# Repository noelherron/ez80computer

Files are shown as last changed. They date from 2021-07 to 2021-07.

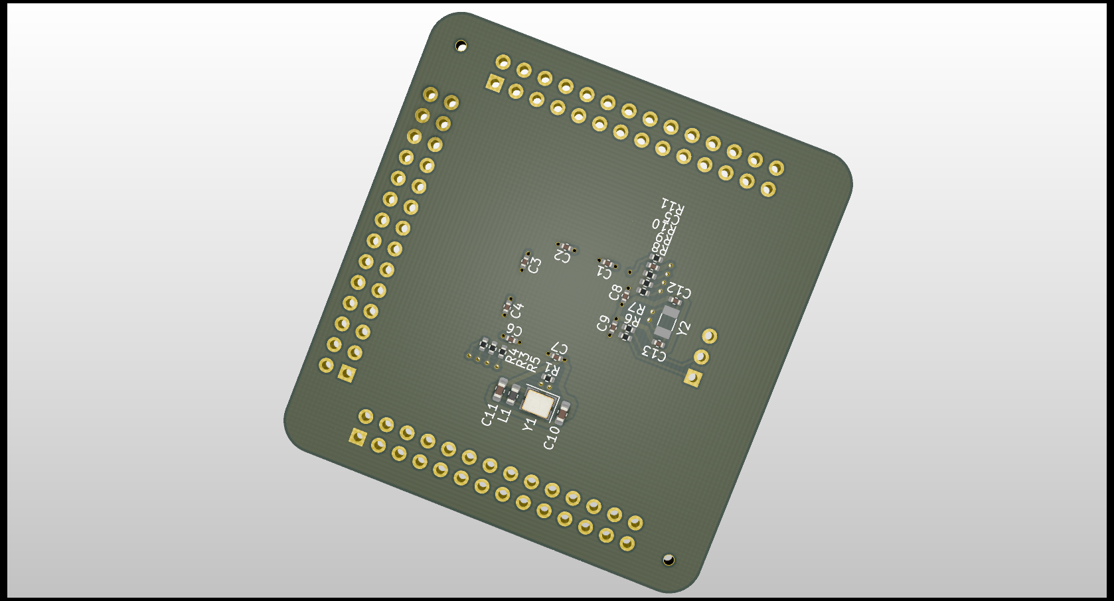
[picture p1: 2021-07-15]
rev0/eZ80SBCrev0.png

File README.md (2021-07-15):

# eZ80Computer

This is a single board computer based on the Zilog eZ80 microcontroller.

The eZ80 was chosen because it is an interesting microcontroller with a deep history.

It's CPU is based on the Z80, which was very popular in the 1980s, and is still manufactured today.

The eZ80 is distinct from many other microcontrollers because it has an exposed address and data bus.

Most microcontrollers have built in memory and omit these pins.

This means we can design our own memory scheme, and learn about things like bus mastering.

Like a traditional microcontroller, it still has many built in periferals, which keeps things small and simple.

This is a learning project for me to better understand electronics, PCB design, and computer system design.

I have already spent many hours in KiCad and had a batch of prototypes made.

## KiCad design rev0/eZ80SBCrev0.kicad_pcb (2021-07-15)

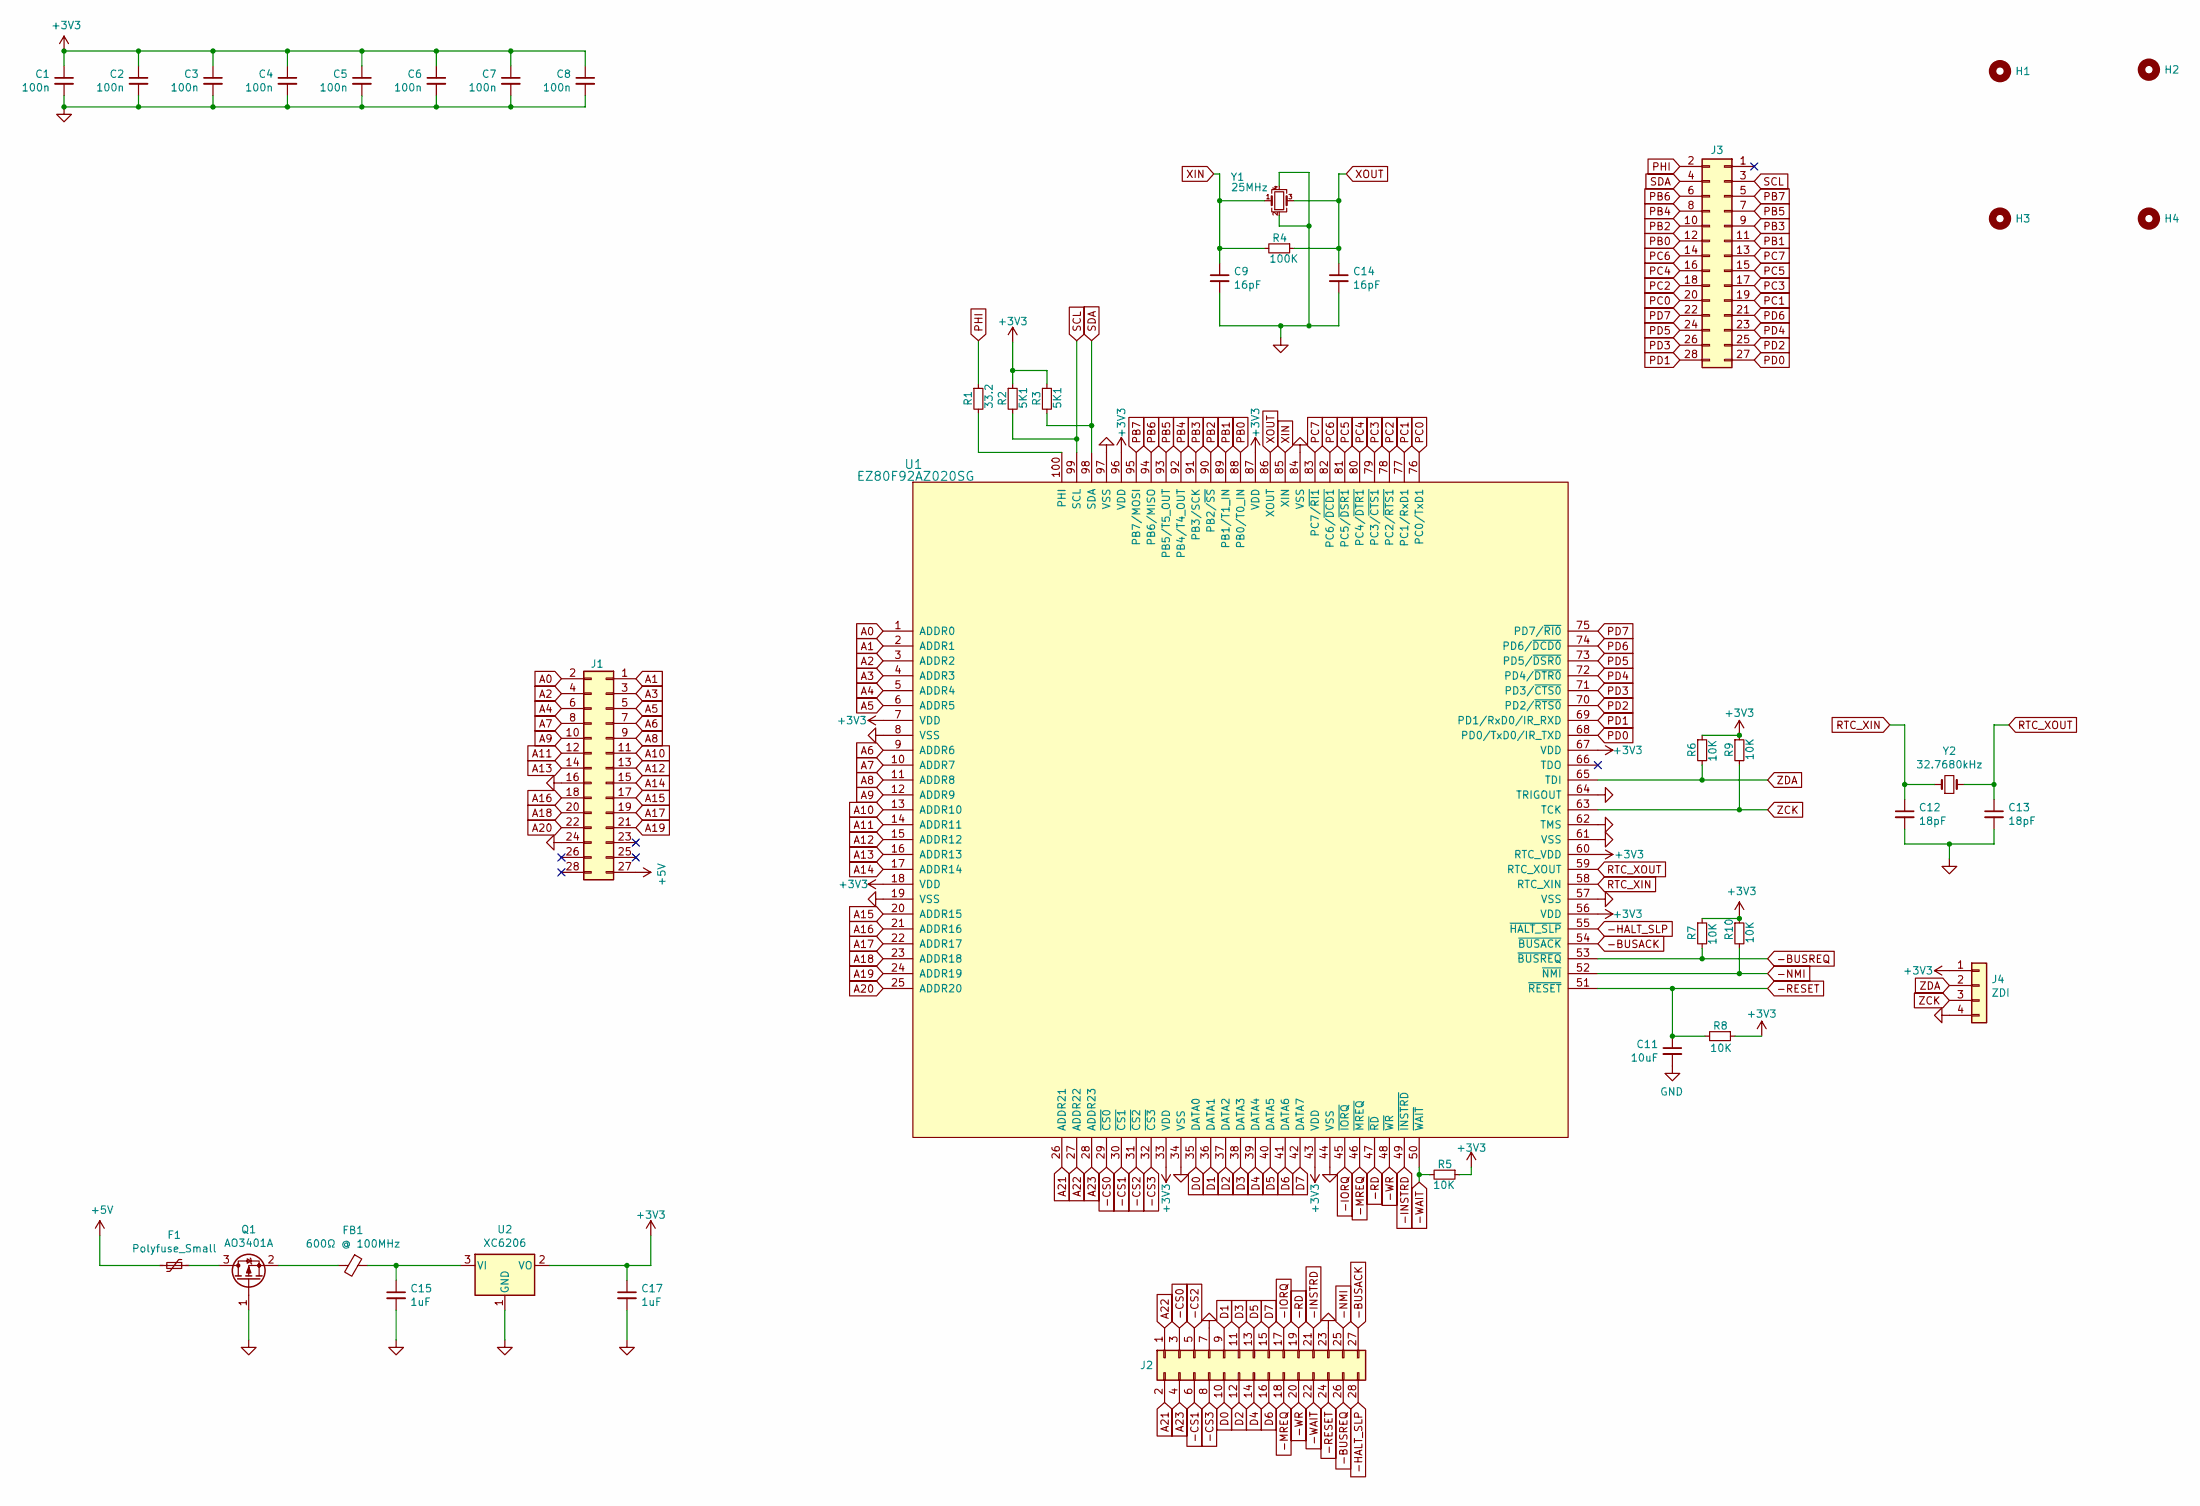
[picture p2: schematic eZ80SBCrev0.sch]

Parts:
C1, C2, C3, C4, C5, C6, C7, C8: 100n; C_0402_1005Metric; MFR. PART# CL05B104KO5NNNC; LCSC C1525
C9, C14: 16pF; C_0805_2012Metric; LCSC C1794
C11: 10uF; C_0402_1005Metric; MFR. PART# CL05A106MQ5NUNC; LCSC C15525
C12, C13: 18pF; C_0402_1005Metric; LCSC C1549
C15, C17: 1uF; C_0805_2012Metric; LCSC C28323
F1: Polyfuse_Small; Fuse_0805_2012Metric
FB1: 600Ω @ 100MHz; L_0805_2012Metric; LCSC C1017
H1, H2, H3, H4: MountingHole; MountingHole_2.1mm
J1, J2, J3: Conn_02x14_Top_Bottom; PinSocket_2x14_P2.54mm_Vertical
J4: ZDI; PinHeader_1x04_P2.54mm_Vertical
Q1: AO3401A; SOT-23; LCSC C15127
R1: 33.2; R_0402_1005Metric; MFR. PART# 0402WGF5101TCE; LCSC C25905
R2, R3: 5K1; R_0402_1005Metric; MFR. PART# 0402WGF5101TCE; LCSC C25905
R4: 100K; R_0805_2012Metric; LCSC C17407
R5, R6, R7, R8, R9, R10: 10K; R_0402_1005Metric; MFR. PART# 0402WGF1002TCE; LCSC C25744
U1: EZ80F92AZ020SG; LQFP-100_14x14mm_P0.5mm
U2: XC6206; SOT-23; LCSC C5446
Y1: 25MHz; SMD-5032-4P; LCSC C9006
Y2: 32.7680kHz; Crystal_SMD_3215-2Pin_3.2x1.5mm; LCSC C32346

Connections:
+3V3: C1.1, C2.1, C3.1, C4.1, C5.1, C6.1, C7.1, C8.1, C17.1, J4.1, R2.1, R3.1, R5.1, R6.1, R7.1, R8.1, R9.1, R10.1, U1.7 (VDD), U1.18 (VDD), U1.33 (VDD), U1.43 (VDD), U1.56 (VDD), U1.60 (RTC_VDD), U1.67 (VDD), U1.87 (VDD), U1.96 (VDD), U2.2 (VO)
+5V: F1.2, J1.27
-BUSACK: J2.27, U1.54 (~BUSACK)
-BUSREQ: J2.26, R7.2, U1.53 (~BUSREQ)
-CS0: J2.3, U1.29 (~CS0)
-CS1: J2.6, U1.30 (~CS1)
-CS2: J2.5, U1.31 (~CS2)
-CS3: J2.8, U1.32 (~CS3)
-HALT_SLP: J2.28, U1.55 (~HALT_SLP)
-INSTRD: J2.21, U1.49 (~INSTRD)
-IORQ: J2.17, U1.45 (~IORQ)
-MREQ: J2.18, U1.46 (~MREQ)
-NMI: J2.25, R10.2, U1.52 (~NMI)
-RD: J2.19, U1.47 (~RD)
-RESET: C11.1, J2.24, R8.2, U1.51 (~RESET)
-WAIT: J2.22, R5.2, U1.50 (~WAIT)
-WR: J2.20, U1.48 (~WR)
A0: J1.2, U1.1 (ADDR0)
A1: J1.1, U1.2 (ADDR1)
A2: J1.4, U1.3 (ADDR2)
A3: J1.3, U1.4 (ADDR3)
A4: J1.6, U1.5 (ADDR4)
A5: J1.5, U1.6 (ADDR5)
A6: J1.7, U1.9 (ADDR6)
A7: J1.8, U1.10 (ADDR7)
A8: J1.9, U1.11 (ADDR8)
A9: J1.10, U1.12 (ADDR9)
A10: J1.11, U1.13 (ADDR10)
A11: J1.12, U1.14 (ADDR11)
A12: J1.13, U1.15 (ADDR12)
A13: J1.14, U1.16 (ADDR13)
A14: J1.15, U1.17 (ADDR14)
A15: J1.17, U1.20 (ADDR15)
A16: J1.18, U1.21 (ADDR16)
A17: J1.19, U1.22 (ADDR17)
A18: J1.20, U1.23 (ADDR18)
A19: J1.21, U1.24 (ADDR19)
A20: J1.22, U1.25 (ADDR20)
A21: J2.2, U1.26 (ADDR21)
A22: J2.1, U1.27 (ADDR22)
A23: J2.4, U1.28 (ADDR23)
D0: J2.10, U1.35 (DATA0)
D1: J2.9, U1.36 (DATA1)
D2: J2.12, U1.37 (DATA2)
D3: J2.11, U1.38 (DATA3)
D4: J2.14, U1.39 (DATA4)
D5: J2.13, U1.40 (DATA5)
D6: J2.16, U1.41 (DATA6)
D7: J2.15, U1.42 (DATA7)
GND: C1.2, C2.2, C3.2, C4.2, C5.2, C6.2, C7.2, C8.2, C9.2, C11.2, C12.2, C13.2, C14.2, C15.2, C17.2, J1.16, J1.24, J2.7, J2.23, J4.4, Q1.1 (G), U1.8 (VSS), U1.19 (VSS), U1.34 (VSS), U1.44 (VSS), U1.57 (VSS), U1.61 (VSS), U1.62 (TMS), U1.64 (TRIGOUT), U1.84 (VSS), U1.97 (VSS), U2.1 (GND), Y1.2, Y1.4
unnamed: C15.1, FB1.1, U2.3 (VI)
unnamed: F1.1, Q1.3 (D)
unnamed: FB1.2, Q1.2 (S)
unnamed: R1.2, U1.100 (PHI)
PB0: J3.12, U1.88 (PB0/T0_IN)
PB1: J3.11, U1.89 (PB1/T1_IN)
PB2: J3.10, U1.90 (PB2/~SS)
PB3: J3.9, U1.91 (PB3/SCK)
PB4: J3.8, U1.92 (PB4/T4_OUT)
PB5: J3.7, U1.93 (PB5/T5_OUT)
PB6: J3.6, U1.94 (PB6/MISO)
PB7: J3.5, U1.95 (PB7/MOSI)
PC0: J3.20, U1.76 (PC0/TxD1)
PC1: J3.19, U1.77 (PC1/RxD1)
PC2: J3.18, U1.78 (PC2/~RTS1)
PC3: J3.17, U1.79 (PC3/~CTS1)
PC4: J3.16, U1.80 (PC4/~DTR1)
PC5: J3.15, U1.81 (PC5/~DSR1)
PC6: J3.14, U1.82 (PC6/~DCD1)
PC7: J3.13, U1.83 (PC7/~RI1)
PD0: J3.27, U1.68 (PD0/TxD0/IR_TXD)
PD1: J3.28, U1.69 (PD1/RxD0/IR_RXD)
PD2: J3.25, U1.70 (PD2/~RTS0)
PD3: J3.26, U1.71 (PD3/~CTS0)
PD4: J3.23, U1.72 (PD4/~DTR0)
PD5: J3.24, U1.73 (PD5/~DSR0)
PD6: J3.21, U1.74 (PD6/~DCD0)
PD7: J3.22, U1.75 (PD7/~RI0)
PHI: J3.2, R1.1
RTC_XIN: C12.1, U1.58 (RTC_XIN), Y2.1
RTC_XOUT: C13.1, U1.59 (RTC_XOUT), Y2.2
SCL: J3.3, R2.2, U1.99 (SCL)
SDA: J3.4, R3.2, U1.98 (SDA)
XIN: C9.1, R4.2, U1.85 (XIN), Y1.1
XOUT: C14.1, R4.1, U1.86 (XOUT), Y1.3
ZCK: J4.3, R9.2, U1.63 (TCK)
ZDA: J4.2, R6.2, U1.65 (TDI)

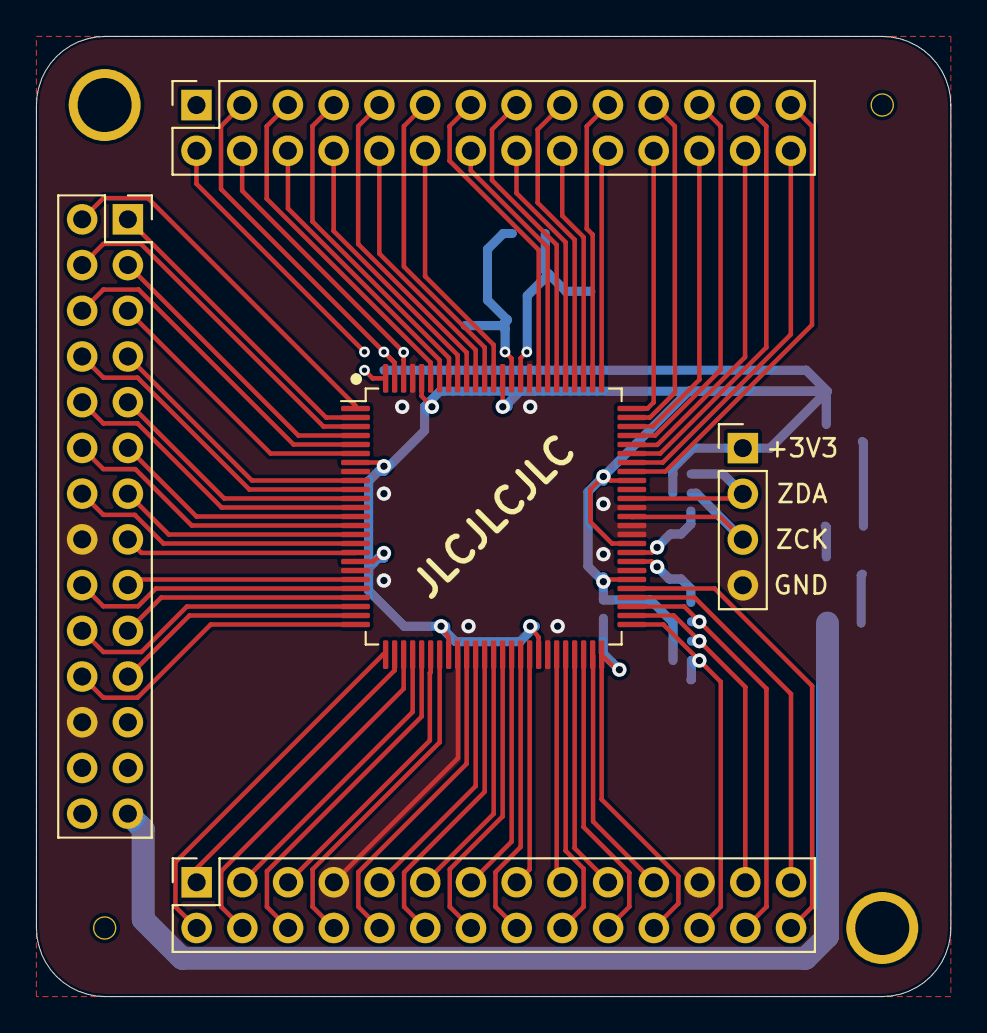
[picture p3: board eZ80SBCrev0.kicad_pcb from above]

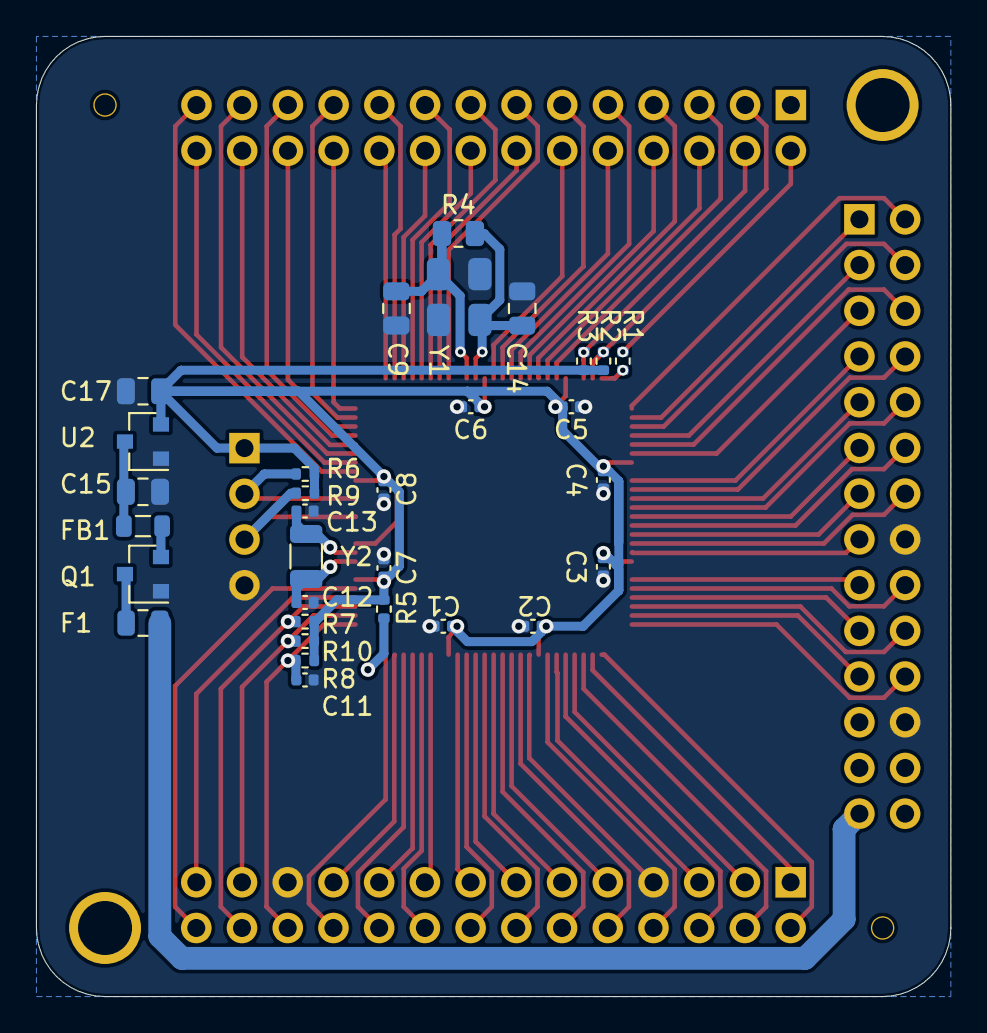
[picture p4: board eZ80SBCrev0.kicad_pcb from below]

Board: 2 copper layers, 50.8 x 53.3 mm, 40 parts (31 on the bottom side), 87 nets.

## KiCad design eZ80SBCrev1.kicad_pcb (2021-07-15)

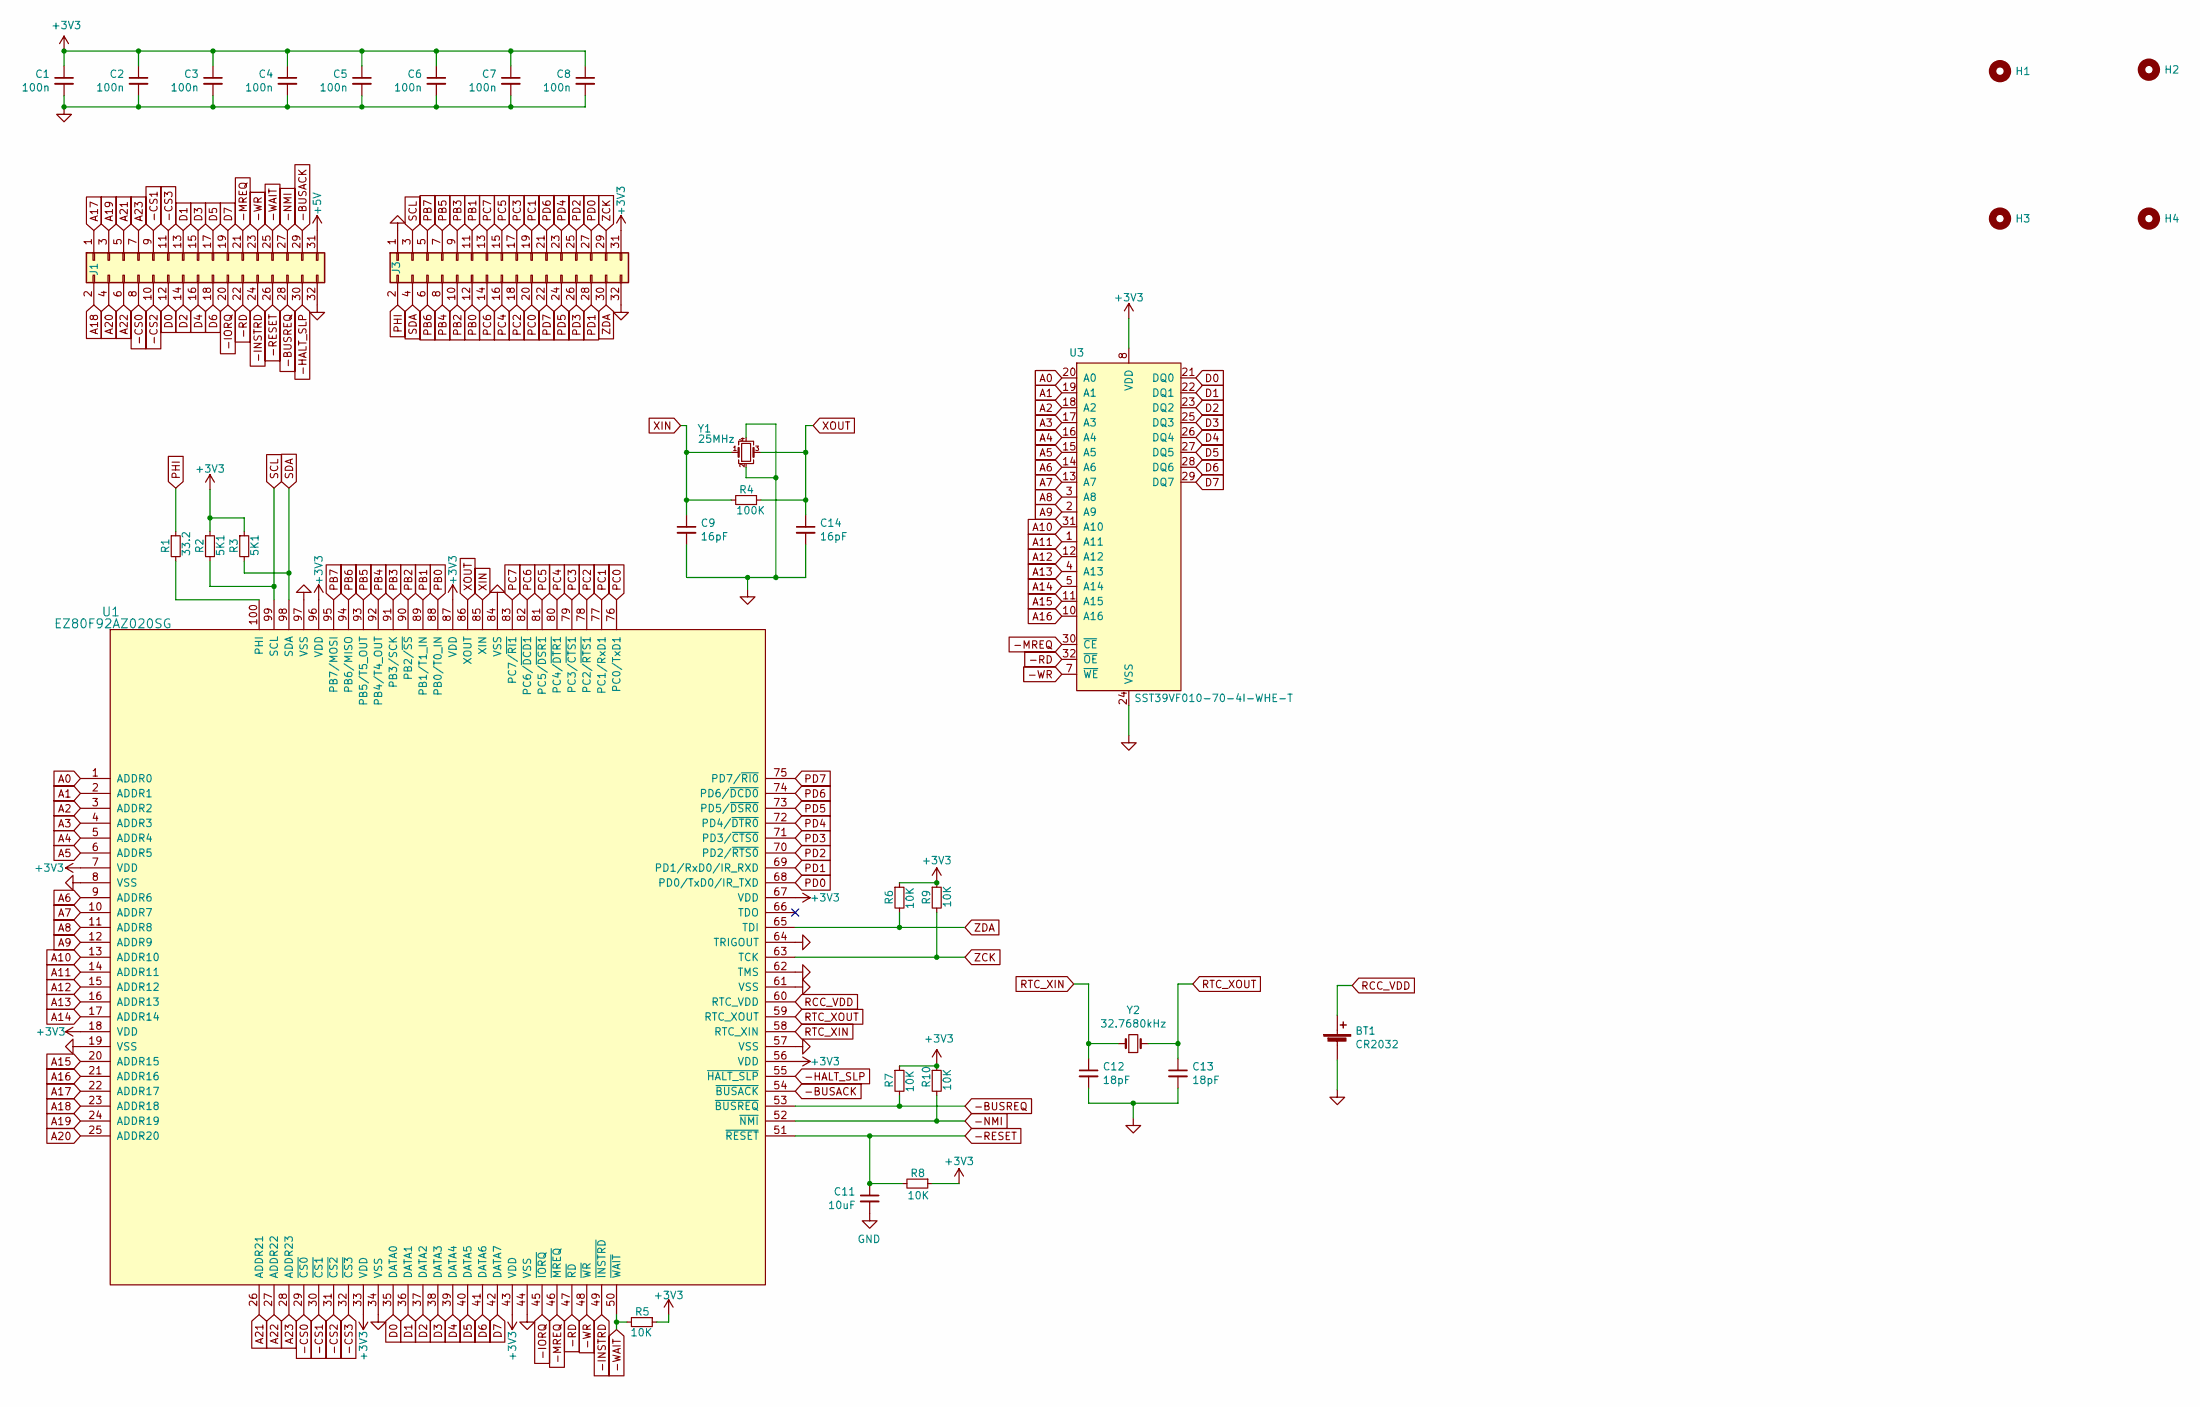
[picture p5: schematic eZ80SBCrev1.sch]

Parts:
BT1: CR2032; BatteryHolder_Keystone_3034_1x20mm
C1, C2, C3, C4, C5, C6, C7, C8: 100n; C_0402_1005Metric; MFR. PART# CL05B104KO5NNNC; LCSC C1525
C9, C14: 16pF; C_0805_2012Metric; LCSC C1794
C11: 10uF; C_0402_1005Metric; MFR. PART# CL05A106MQ5NUNC; LCSC C15525
C12, C13: 18pF; C_0402_1005Metric; LCSC C1549
H1, H2, H3, H4: MountingHole; MountingHole_2.1mm
J1, J3: Conn_02x16_Top_Bottom; PinSocket_2x16_P2.54mm_Vertical
R1: 33.2; R_0402_1005Metric; MFR. PART# 0402WGF5101TCE; LCSC C25905
R2, R3: 5K1; R_0402_1005Metric; MFR. PART# 0402WGF5101TCE; LCSC C25905
R4: 100K; R_0805_2012Metric; LCSC C17407
R5, R6, R7, R8, R9, R10: 10K; R_0402_1005Metric; MFR. PART# 0402WGF1002TCE; LCSC C25744
U1: EZ80F92AZ020SG; LQFP-100_14x14mm_P0.5mm
U3: SST39VF010-70-4I-WHE-T; TSOP-I-32_11.8x8mm_P0.5mm
Y1: 25MHz; SMD-5032-4P; LCSC C9006
Y2: 32.7680kHz; Crystal_SMD_3215-2Pin_3.2x1.5mm; LCSC C32346

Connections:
+3V3: C1.1, C2.1, C3.1, C4.1, C5.1, C6.1, C7.1, C8.1, J3.31, R2.1, R3.1, R5.1, R6.1, R7.1, R8.1, R9.1, R10.1, U1.7 (VDD), U1.18 (VDD), U1.33 (VDD), U1.43 (VDD), U1.56 (VDD), U1.67 (VDD), U1.87 (VDD), U1.96 (VDD), U3.8 (VDD)
-BUSACK: J1.29, U1.54 (~BUSACK)
-BUSREQ: J1.28, R7.2, U1.53 (~BUSREQ)
-CS0: J1.8, U1.29 (~CS0)
-CS1: J1.9, U1.30 (~CS1)
-CS2: J1.10, U1.31 (~CS2)
-CS3: J1.11, U1.32 (~CS3)
-HALT_SLP: J1.30, U1.55 (~HALT_SLP)
-INSTRD: J1.24, U1.49 (~INSTRD)
-IORQ: J1.20, U1.45 (~IORQ)
-MREQ: J1.21, U1.46 (~MREQ), U3.30 (~CE)
-NMI: J1.27, R10.2, U1.52 (~NMI)
-RD: J1.22, U1.47 (~RD), U3.32 (~OE)
-RESET: C11.1, J1.26, R8.2, U1.51 (~RESET)
-WAIT: J1.25, R5.2, U1.50 (~WAIT)
-WR: J1.23, U1.48 (~WR), U3.7 (~WE)
A0: U1.1 (ADDR0), U3.20 (A0)
A1: U1.2 (ADDR1), U3.19 (A1)
A2: U1.3 (ADDR2), U3.18 (A2)
A3: U1.4 (ADDR3), U3.17 (A3)
A4: U1.5 (ADDR4), U3.16 (A4)
A5: U1.6 (ADDR5), U3.15 (A5)
A6: U1.9 (ADDR6), U3.14 (A6)
A7: U1.10 (ADDR7), U3.13 (A7)
A8: U1.11 (ADDR8), U3.3 (A8)
A9: U1.12 (ADDR9), U3.2 (A9)
A10: U1.13 (ADDR10), U3.31 (A10)
A11: U1.14 (ADDR11), U3.1 (A11)
A12: U1.15 (ADDR12), U3.12 (A12)
A13: U1.16 (ADDR13), U3.4 (A13)
A14: U1.17 (ADDR14), U3.5 (A14)
A15: U1.20 (ADDR15), U3.11 (A15)
A16: U1.21 (ADDR16), U3.10 (A16)
A17: J1.1, U1.22 (ADDR17)
A18: J1.2, U1.23 (ADDR18)
A19: J1.3, U1.24 (ADDR19)
A20: J1.4, U1.25 (ADDR20)
A21: J1.5, U1.26 (ADDR21)
A22: J1.6, U1.27 (ADDR22)
A23: J1.7, U1.28 (ADDR23)
D0: J1.12, U1.35 (DATA0), U3.21 (DQ0)
D1: J1.13, U1.36 (DATA1), U3.22 (DQ1)
D2: J1.14, U1.37 (DATA2), U3.23 (DQ2)
D3: J1.15, U1.38 (DATA3), U3.25 (DQ3)
D4: J1.16, U1.39 (DATA4), U3.26 (DQ4)
D5: J1.17, U1.40 (DATA5), U3.27 (DQ5)
D6: J1.18, U1.41 (DATA6), U3.28 (DQ6)
D7: J1.19, U1.42 (DATA7), U3.29 (DQ7)
GND: BT1.2 (-), C1.2, C2.2, C3.2, C4.2, C5.2, C6.2, C7.2, C8.2, C9.2, C11.2, C12.2, C13.2, C14.2, J1.32, J3.1, J3.32, U1.8 (VSS), U1.19 (VSS), U1.34 (VSS), U1.44 (VSS), U1.57 (VSS), U1.61 (VSS), U1.62 (TMS), U1.64 (TRIGOUT), U1.84 (VSS), U1.97 (VSS), U3.24 (VSS), Y1.2, Y1.4
unnamed: R1.2, U1.100 (PHI)
PB0: J3.12, U1.88 (PB0/T0_IN)
PB1: J3.11, U1.89 (PB1/T1_IN)
PB2: J3.10, U1.90 (PB2/~SS)
PB3: J3.9, U1.91 (PB3/SCK)
PB4: J3.8, U1.92 (PB4/T4_OUT)
PB5: J3.7, U1.93 (PB5/T5_OUT)
PB6: J3.6, U1.94 (PB6/MISO)
PB7: J3.5, U1.95 (PB7/MOSI)
PC0: J3.20, U1.76 (PC0/TxD1)
PC1: J3.19, U1.77 (PC1/RxD1)
PC2: J3.18, U1.78 (PC2/~RTS1)
PC3: J3.17, U1.79 (PC3/~CTS1)
PC4: J3.16, U1.80 (PC4/~DTR1)
PC5: J3.15, U1.81 (PC5/~DSR1)
PC6: J3.14, U1.82 (PC6/~DCD1)
PC7: J3.13, U1.83 (PC7/~RI1)
PD0: J3.27, U1.68 (PD0/TxD0/IR_TXD)
PD1: J3.28, U1.69 (PD1/RxD0/IR_RXD)
PD2: J3.25, U1.70 (PD2/~RTS0)
PD3: J3.26, U1.71 (PD3/~CTS0)
PD4: J3.23, U1.72 (PD4/~DTR0)
PD5: J3.24, U1.73 (PD5/~DSR0)
PD6: J3.21, U1.74 (PD6/~DCD0)
PD7: J3.22, U1.75 (PD7/~RI0)
PHI: J3.2, R1.1
RCC_VDD: BT1.1 (+), U1.60 (RTC_VDD)
RTC_XIN: C12.1, U1.58 (RTC_XIN), Y2.1
RTC_XOUT: C13.1, U1.59 (RTC_XOUT), Y2.2
SCL: J3.3, R2.2, U1.99 (SCL)
SDA: J3.4, R3.2, U1.98 (SDA)
XIN: C9.1, R4.2, U1.85 (XIN), Y1.1
XOUT: C14.1, R4.1, U1.86 (XOUT), Y1.3
ZCK: J3.29, R9.2, U1.63 (TCK)
ZDA: J3.30, R6.2, U1.65 (TDI)

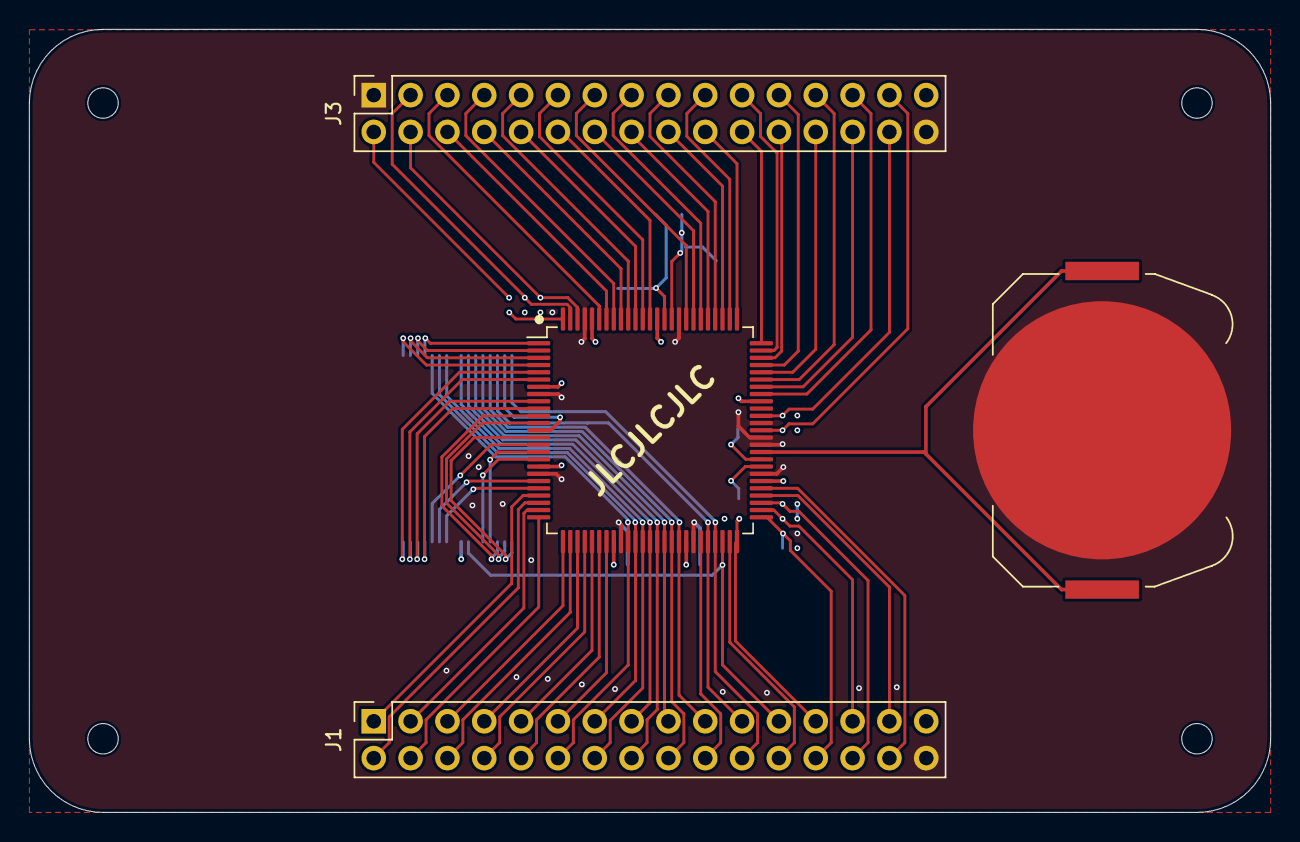
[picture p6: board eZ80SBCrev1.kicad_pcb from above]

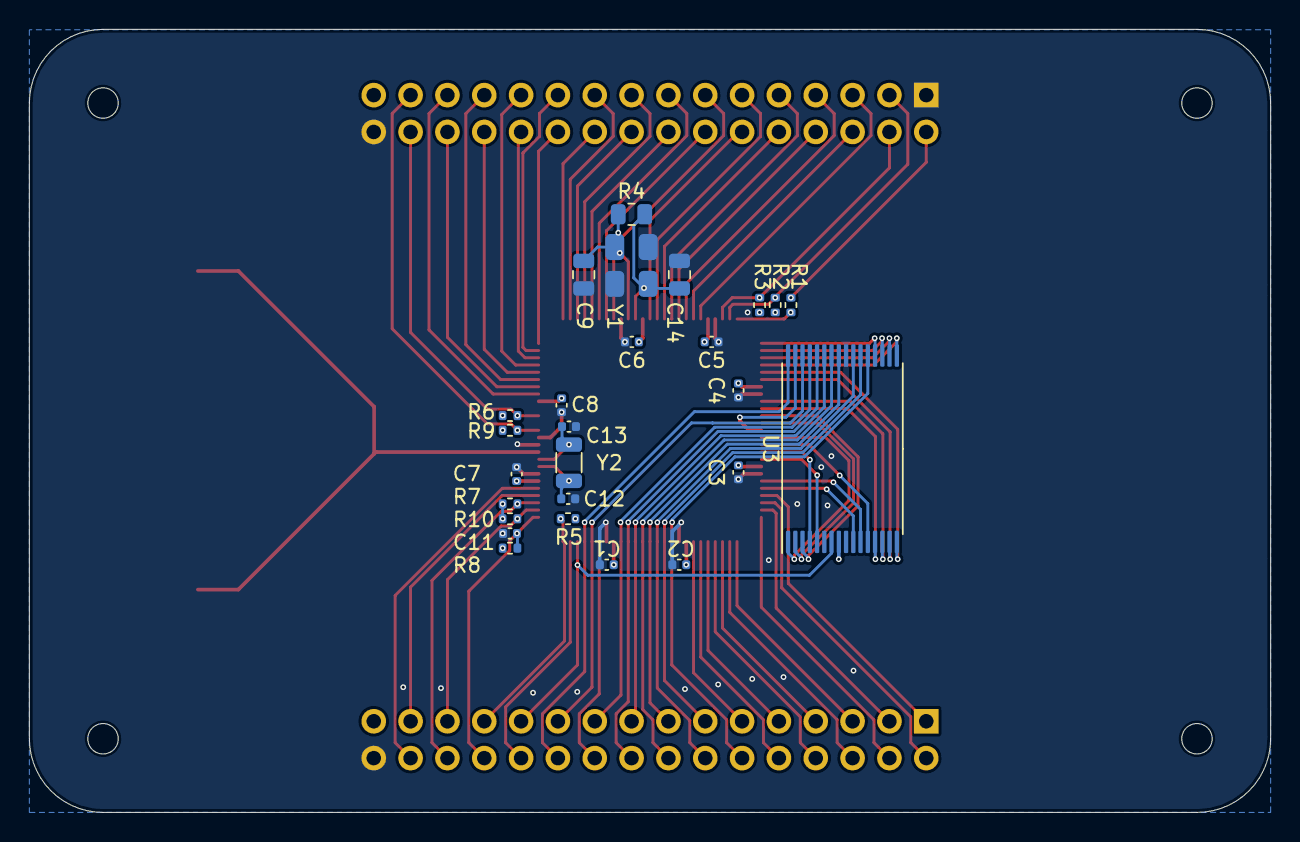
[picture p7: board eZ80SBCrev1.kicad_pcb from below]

Board: 4 copper layers, 85.6 x 54.0 mm, 34 parts (26 on the bottom side), 84 nets.
